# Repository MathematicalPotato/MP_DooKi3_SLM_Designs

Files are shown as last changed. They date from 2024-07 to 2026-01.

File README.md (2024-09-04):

# SLM parts for the X, Y, and Z Axis of DooKi3 or Annex Engineering K3
These files are designed to be SLM printed out of aluminum.  All files in this repo are still a WIP.  Do not order parts unless you are prepared for post-processing ill-fitting parts or worst-case scraping a whole batch of parts.

### !!! Please read all the notes in the READMEs for any parts you plan to order. !!!

## Notes
Please use the STLs for printing.  The CAD/STEP files are available in the event modifications are necessary for certain setups, but some print services cannot import STEP files and certain CAD files have been uploaded as assemblies and will not print properly if directly imported into print services.

There are a few different versions of the tensioning slider with different clearances.  At this time it is recommended to get the thickest version (+0.15) and sand to size. The machine will need a minimum of 7 tensioning sliders (4 for XY and 3 for Z).  As of August 20th 2024 the Z tensioners have been updated to V3 to allow for the use of up to 10mm belts and the XY tensioners have been updated to V4 to allow for the use of either 9/10mm belts or 12mm belts.  This 10mm version is recommended even for 9mm belts and requires the 10mm tensioning sliders. 9/10mm belts will also work with the 12mm parts, but they will be slightly heavier and won't have any othewr benefits besides allowing the use of 12mm belt.

## SLM XY Idlers - Live shafts and full sized pulleys:
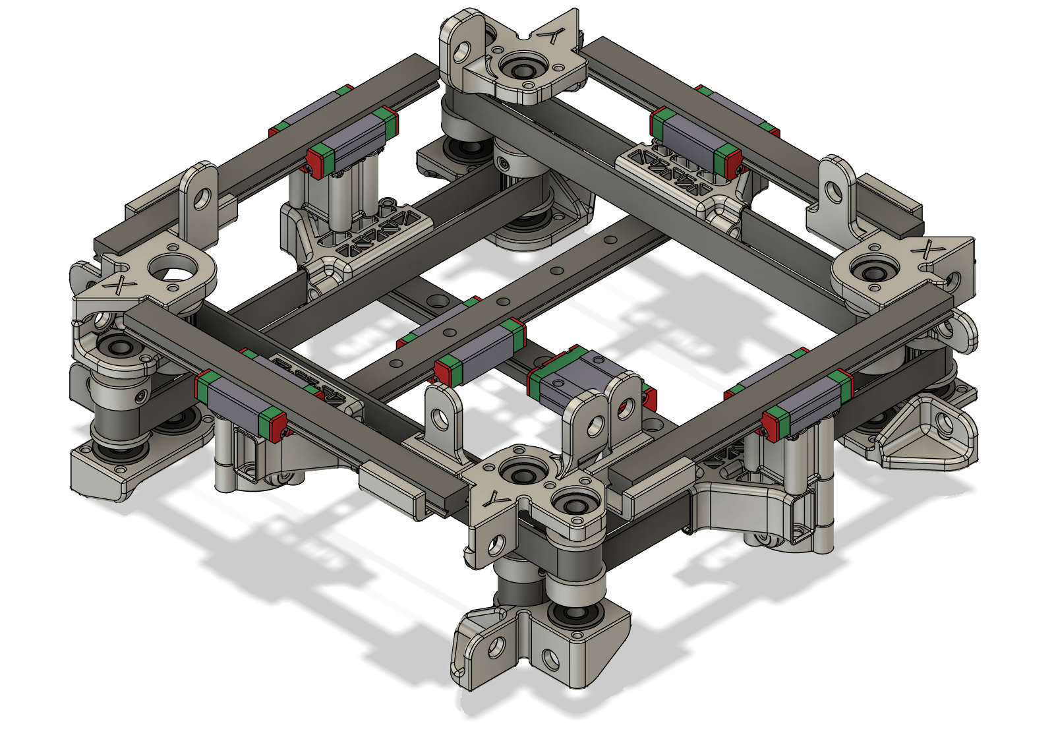
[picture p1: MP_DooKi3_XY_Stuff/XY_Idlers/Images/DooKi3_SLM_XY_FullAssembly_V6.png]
DooKi3_SLM_XY_Assembly

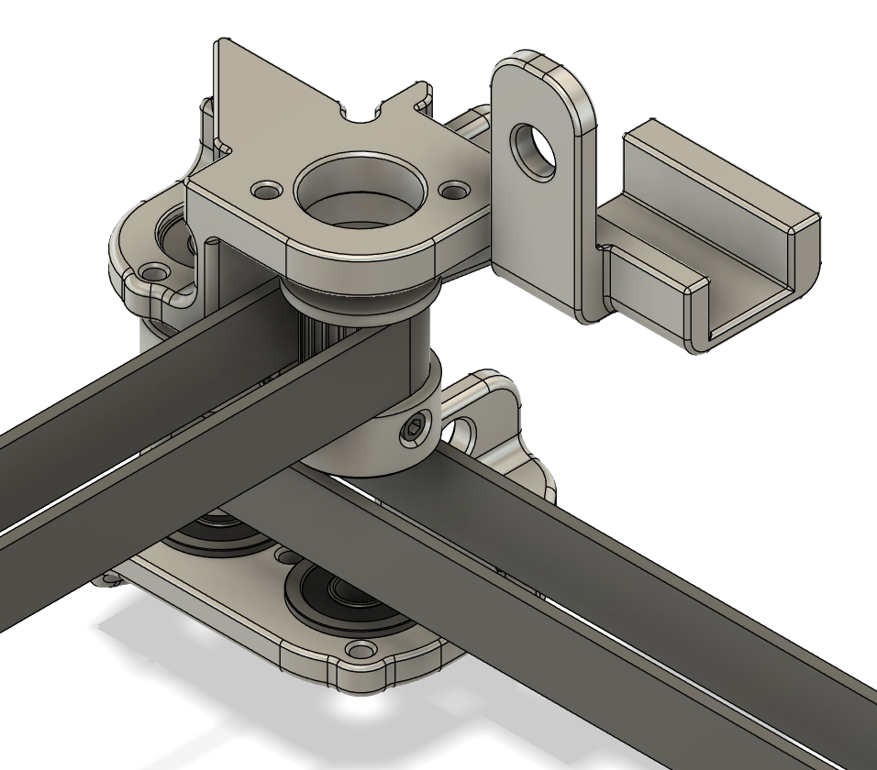
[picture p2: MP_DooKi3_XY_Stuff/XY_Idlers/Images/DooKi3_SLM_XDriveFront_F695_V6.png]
DooKi3_SLM_XDrive_F695

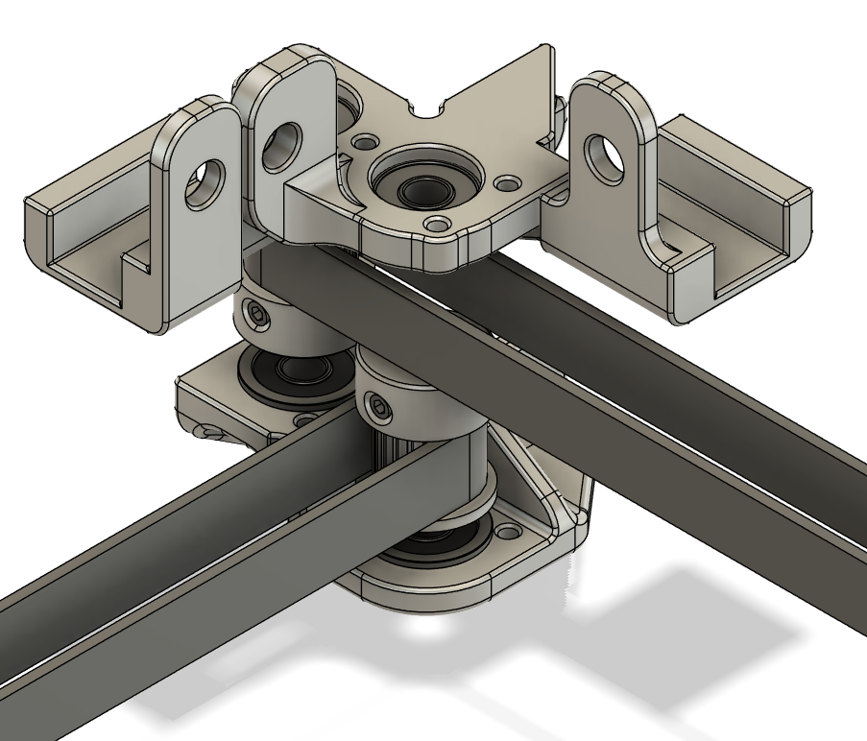
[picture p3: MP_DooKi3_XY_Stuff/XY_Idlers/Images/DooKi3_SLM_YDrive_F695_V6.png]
DooKi3_SLM_YDrive_F695


## SLM XY Tensioners
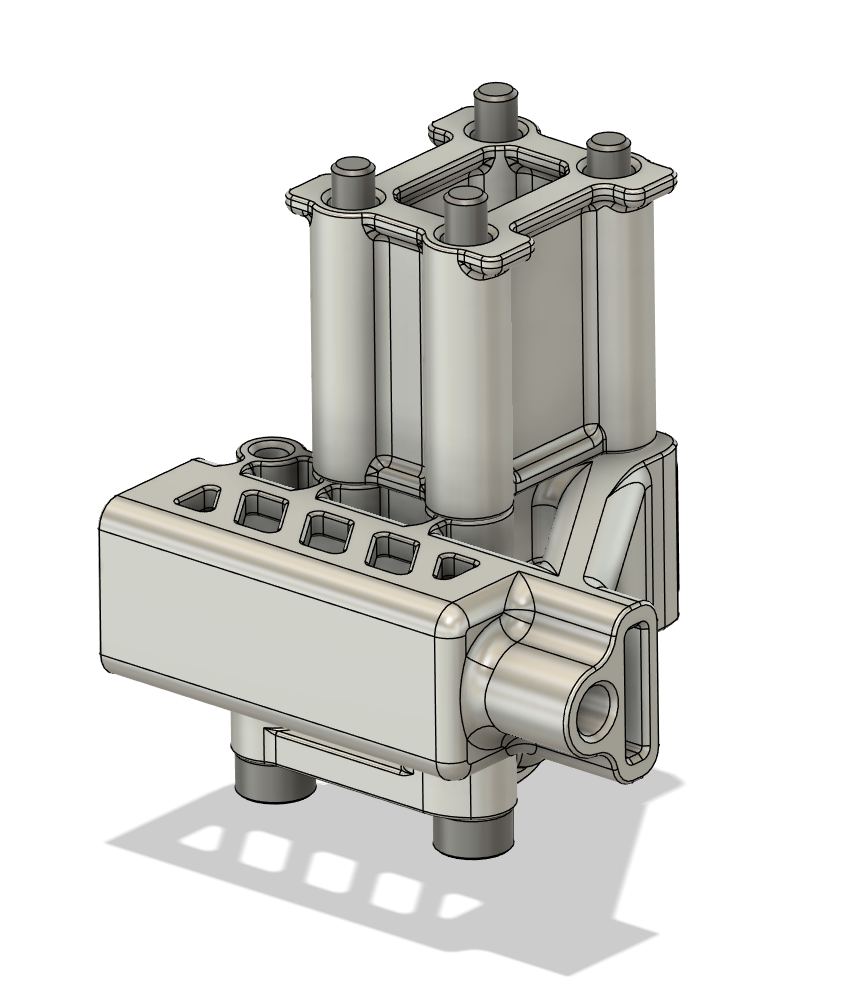
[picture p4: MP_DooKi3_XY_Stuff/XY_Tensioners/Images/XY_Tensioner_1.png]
XY_Tensioner_1

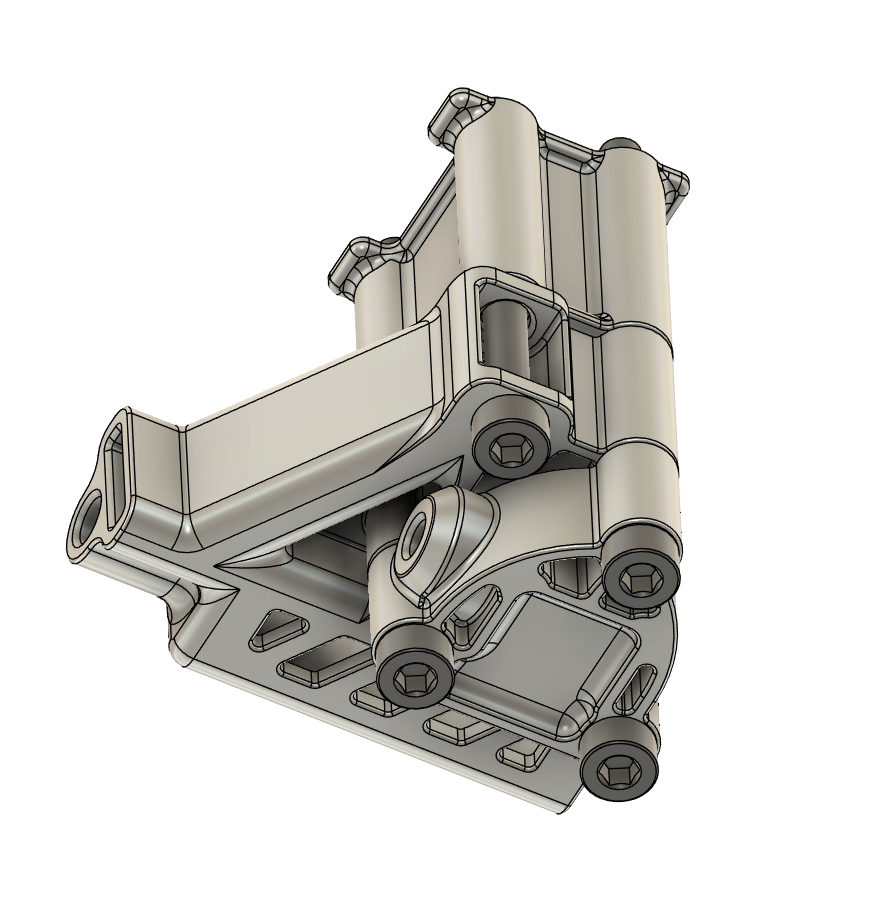
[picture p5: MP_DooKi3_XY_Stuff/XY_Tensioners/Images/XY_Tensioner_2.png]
XY_Tensioner_2

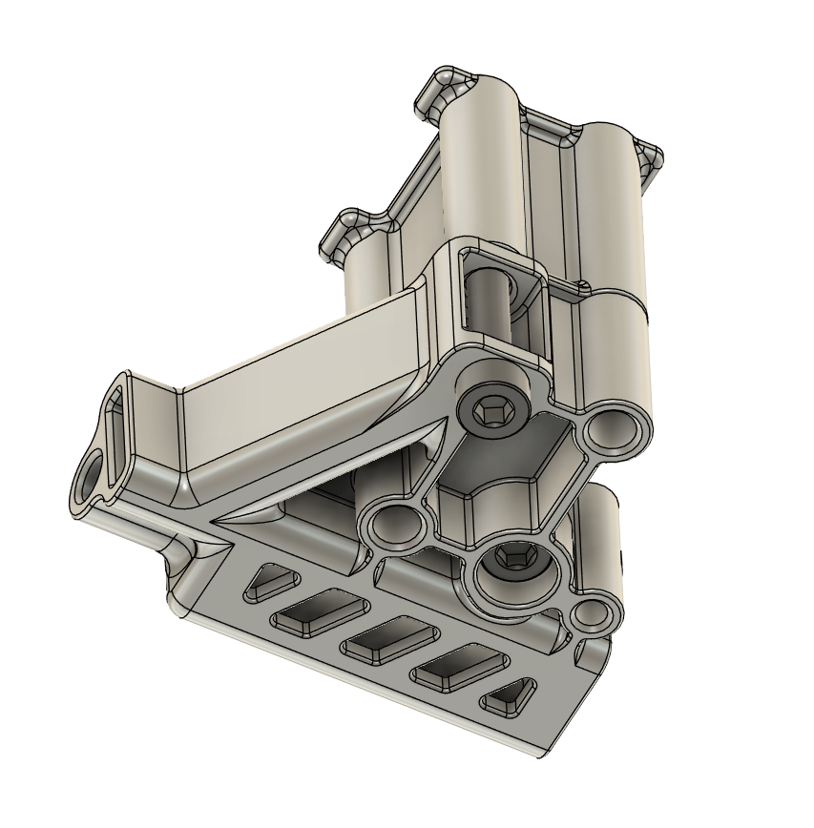
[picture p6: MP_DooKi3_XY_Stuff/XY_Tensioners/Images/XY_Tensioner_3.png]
XY_Tensioner_3


## SLM Z Maxwell Mounts and MGN9C Carriages
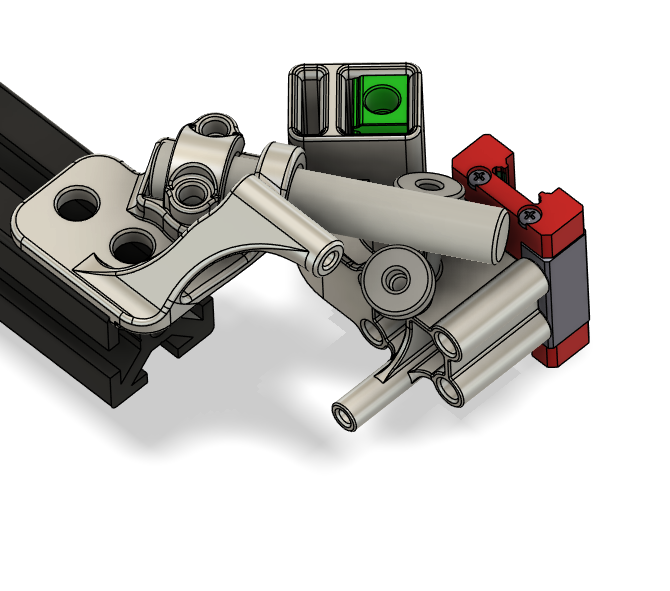
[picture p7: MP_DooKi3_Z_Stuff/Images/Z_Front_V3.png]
Z_Front

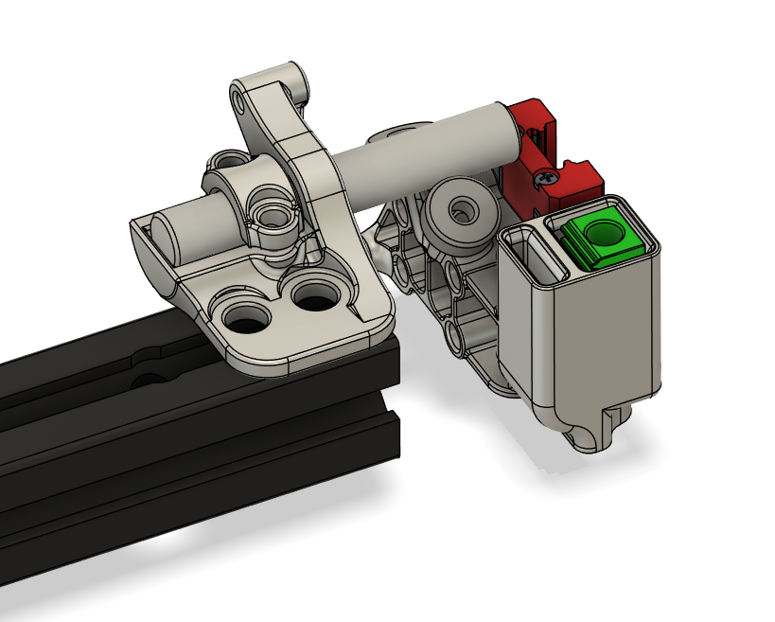
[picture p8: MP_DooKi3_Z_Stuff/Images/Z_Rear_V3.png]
Z_Rear


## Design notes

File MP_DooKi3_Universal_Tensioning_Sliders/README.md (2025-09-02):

# SLM Tensioning Sliders for X, Y, and Z Axes
These files are designed to be SLM printed out of aluminum.

## Notes
There are versions for 10mm (also compatible with 9mm) and 12mm belts.  Ensure you print the version for your XY setup.

These parts are oversized.  They will likely need sanded (on the side opposite the teeth) to ensure proper fitment belt retention.

Four sliders each have been combined into a single file for easier/cheaper printing.  They will need cut apart and sanded/filed to remove connecting the nubs. The Z Assembly will require one 10mm and XY will require either one 10mm or one 12mm depending on the XY tensioners ordered.

## Updates
### 2025-09-02
- Updated to V2
  - Added lightenting cutouts to make sanding to size easier and also reduce total part weight.

### 2024-09-26
- Updated thickness of sliders to require less sanding.

### 2024-08-20
- Updated to 4x combined sliders for 10mm and 12mm.

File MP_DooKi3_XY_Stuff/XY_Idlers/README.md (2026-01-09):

# SLM Printable XY Idlers for the Annex Engineering K3
These drives are designed to be SLM printed in aluminum (or other metals for $$$).  They allow for the toothed idlers to be changed to a full sized pulley with double shear.  Full sized bearings can take a lot more load than the smaller toothed idler bearings.  This should allow for full tension GT3 belts.

## Important Note

All bearings have been swapped to F695 (5mm shaft) or MF148 (8mm shaft).

The bearing holes are intentionally undersized.  In order to get a snug fit, you will need to first drill and then ream the holes to size.  All bearing locations have holes for M3 bolts for retention.  It is recommended to use M3x4 or M3x5 Button Head Cap Screws (BHCS).  There are 16 bearing locations and each will need 2-3 retaining bolts.  Retaining compound can also be used, but may make bearing removal difficult to impossible depending on the breakdown temperature of the compound used. 

The lower idler bodies will interfere with the stock FDM printed Z idlers.  It is recommended to only use these parts if you also have the SLM Z parts.

The endstops have been modeled together as one part to reduce print costs, the number of files, and to ensure they are matching heights.  The finished parts will need to be cut apart and sanded flat.  Only sand where the connecting nubs are present to avoid altering the overall length of the parts. 

### Approximate part weights
- MP_DooKi3_SLM_XY_V6_XDrive_Top: 18.1g
- MP_DooKi3_SLM_XY_V6_XDrive_BottomFront: 13.6g
- MP_DooKi3_SLM_XY_V6_XDrive_BottomRear: 13.1g
- MP_DooKi3_SLM_XY_V6_YDrive_Top: 15.6g
- MP_DooKi3_SLM_XY_V6_YDrive_Bottom: 17.5g
- MP_DooKi3_SLM_XY_V6_Endstops: 35g

## BOM
These lists are the recommended configurations for each belt setup.
### 9 or 10mm GT2 or GT3 belts
In addition to the stock four GT2 9mm pulleys you will need:
- 16 - F695 bearings for 5mm shafts
- 4 - additional GT2 9mm Pulleys with 5mm bore
- 4 - 37mm D cut 5mm diameter shafts (for the idler pulley)

### 12mm GT2 belts

IF YOU USE 12MM BELTS THE FOUR PULLEYS USED FOR THE DRIVE (MOTOR) SHAFTS WILL NEED APPROXIMATELY 1-2MM GROUND OFF THE BOTTOM (SET SCREW END) IN ORDER TO AVOID INTERFERENCE WITH THE BELTS.

In addition to the stock four GT2 9mm pulleys you will need:
- 16 - F695 bearings for 5mm shafts
- 4 - additional GT2 9mm pulleys with 5mm bore
- 4 - 37mm D cut 5mm diameter shafts (for the idler pulley)

### 12mm GT3 belts

1. IF YOU USE 12MM BELTS THE FOUR PULLEYS USED FOR THE DRIVE (MOTOR) SHAFTS WILL NEED APPROXIMATELY 1-2MM GROUND OFF THE BOTTOM (SET SCREW END) IN ORDER TO AVOID INTERFERENCE WITH THE BELTS.
2. 12MM GT3 BELTS REQUIRE VERY HIGH TENSION.  THIS SETUP IS NOT RECOMMENDED FOR STOCK 2020 K3 FRAMES.  A DooKi3-STYLE 4040 FRAME WOULD BE BETTER SUITED.

You will need:
- 16 - MF148 bearings for 8mm shafts
- 8 - additional GT2 12mm pulleys with 8mm bore.
- 4 - 37mm D cut 8mm diameter shafts (for the idler pulley)
- 4 - 60mm D cut 8mm diameter shafts (for drive pulley)
- 4 - Couplers to attach the motor, see Annex BOM for recommendations

## Updates
### 2024-10-12
- Reuploaded XDrive_BottomRear
  - Fixed half-broken chamfers.
### 2024-08-20
- Updated parts to V6
  - Converted to two part idlers instead of single part.  This should make them easier to print and post process (drill ream).
  - All parts now have holes where button-head cap screws (BHCS) can be used to retain the bearings.
  - The endstops have been combined into one printable file.
  - There are two lower parts for the X drives. One for the front left drive and one for the rear right drive. 

### 2024-08-07
- Reorganized the outdated parts folder and added version numbers for better tracking.
  - V1 are the original files
  - V2 have updated clearances and should be slightly lighter
- Updated XY idlers to V3 to allow for better clearances.
  - V3 will need the left Y rail shifted 10.5mm towards the front of the machine and the right Y rail shifted 10.5mm towards the rear of the machine.  This will allow for the idler stacks to be more easily removeable like the current Annex Engineering K3 625 bearing mounts.  All of the mounting bolts are oriented to thread into T-nuts in the vertical extrusions so shorter than standard allen wrenches are no longer needed.

## Images
### XY Assembly:
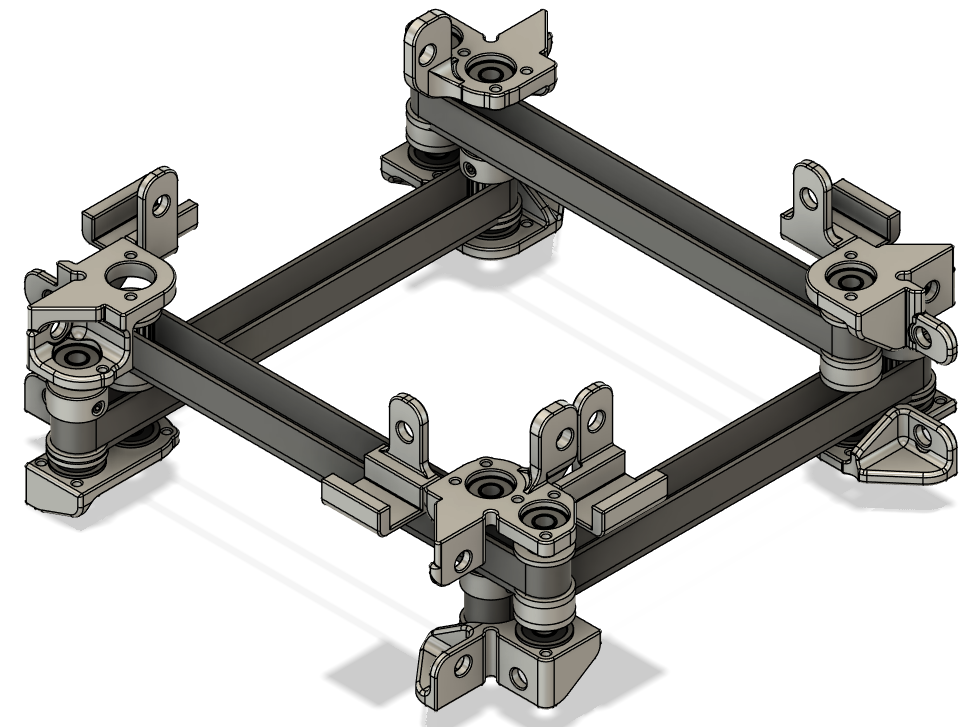
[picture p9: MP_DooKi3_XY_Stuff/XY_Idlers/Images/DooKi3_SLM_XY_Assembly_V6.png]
DooKi3_SLM_XY_Assembly


### X Drive:
DooKi3_SLM_XDriveFront_F695
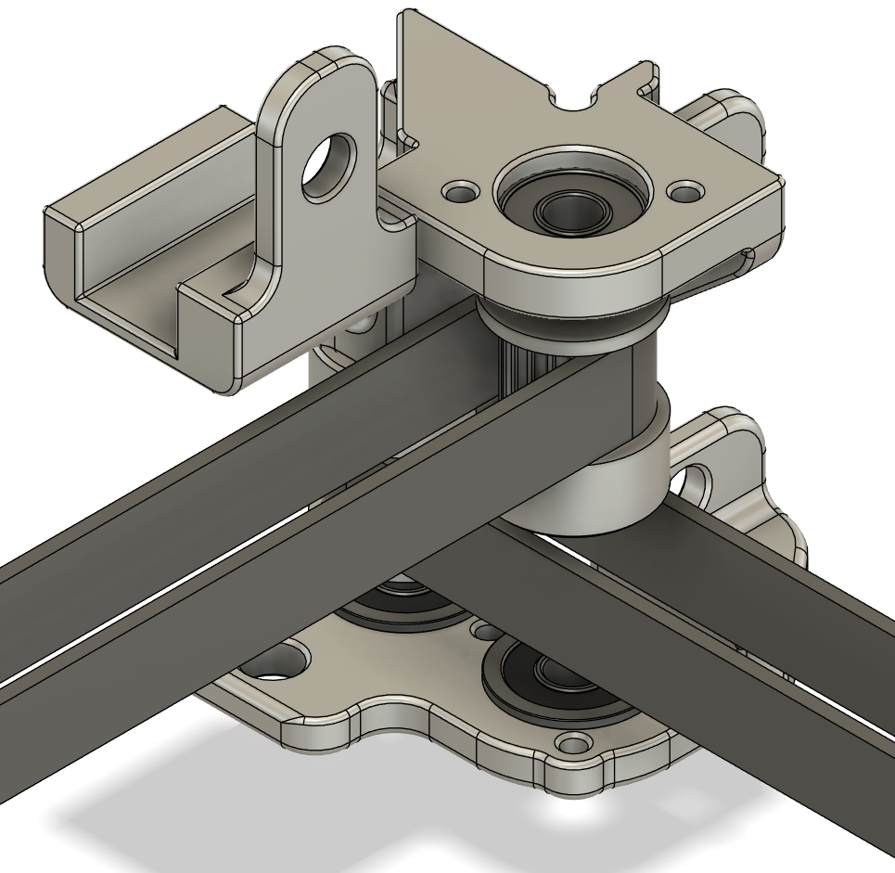
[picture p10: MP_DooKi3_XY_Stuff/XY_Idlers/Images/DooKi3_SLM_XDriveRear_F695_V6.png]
DooKi3_SLM_XDriveRear_F695


### Y Drive:
DooKi3_SLM_YDrive_F695

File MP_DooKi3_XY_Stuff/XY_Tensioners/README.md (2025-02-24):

# SLM XY Tensioner Stack for the Z Axis of DooKi3 or Annex Engineering K3
These files are designed to be SLM printed out of aluminum.

## Notes
There are Y Spacers are modeled as 20 or 21mm tall.  I orderd the 20mm and they came out as 20.3-20.4mm.  They will need sanded to the correct dimensions based on the rails and toolhead used for the machine.
The following Y Spacer thicknesses are required for a total toolhead plate thickness of 6.4mm: 
6.5mm thick rails = 19.9mm
6.0mm thick rails = 20.4mm
5.6mm thick rails = 20.8mm

The rail carriage mount only uses three bolts.  This allows the tensioner to remain installed with two bolts while the cross rails are removed so belt tension can be preserved during maintenance. There are many rail thickness options, it is recommended to get the size for your specific rails, however the smaller ones can be used with thicker rails if needed.  The larger options would need shims on the rails to work with smaller rails so it is not recommended to oversize.

These should be the approximate weights for these parts in aluminum:
- MP_DooKi3_SLM_XY_Tensioner_V4_10mm: 13.9g
- MP_DooKi3_SLM_XY_Tensioner_V4_12mm: 15.6g
- MP_DooKi3_SLM_XY_Rail_Mount_V2: 3.9g
- MP_DooKi3_SLM_Y_Spacer_V2: 6.2g

Total:
- 10mm X total: 17.8g per side
- 10mm Y total: 24.0g per side
- 12mm X total: 19.5g per side
- 12mm Y total: 25.7g per side

## Updates
### 2025-02-24
- Added additional rail mount sizes
  - 5.0mm thick rails
  - 5.5mm thick rails

### 2025-02-20
- Added additional rail mount sizes
  - 5.6mm thick rails
  - 6.0mm thick rails
- Added 21mm thick Y spacer

### 2024-10-29
- Updated tensioners to V6.
  - Increased wall thickness for 2.4mm tapping holes to allow better fitment for helicoils.

### 2024-09-06
- Updated tensioners to V5.
  - Widened belt slots to improve fitment and ease of insertion.
- Updated rail mounts to V4.
  - Widened rail and magnet spaces for better fitment and clearances.
 
### 2024-08-20
- Updated tensioners to V4.
  - This version adds tensioning parts that are compatible with 12mm wide belts.
    - 12mm will require the SLM idlers here: https://github.com/MathematicalPotato/MP_DooKi3_SLM_Designs/tree/main/MP_DooKi3_XY_Stuff/XY_Idlers.  See the README for additional considerations. 
  - This version mainly included CAD workflow changes to make the tensioners easier to modify in the future.  This version is slightly heavier as a result.

### 2024-08-07
- Reorganized the outdated parts folder and added version numbers for better tracking.
  - V1 are the original files.
  - V2 have updated clearances and should be slightly lighter.
- Updated XY tensioners to V3 to allow for the use of up to 10mm wide belts.
  - This version is also compatible with 9mm belts and is recommended for all belt thicknesses.
  - This version will require the use of the 10mm versions of the tensioning sliders.

## Images
XY_Tensioner_1
XY_Tensioner_2
XY_Tensioner_3

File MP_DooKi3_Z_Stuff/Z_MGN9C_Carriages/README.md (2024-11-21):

# SLM Z MGN9C Carriage Mounts for the Z Axis of DooKi3 or Annex Engineering K3
These files are designed to be SLM printed out of aluminum.

## Notes
Fronts will need M3x20 bolts for mounting instead of the stock M3x25.

These should be the approximate weights for these parts in aluminum:
- MP_DooKi3_SLM_Z_MGN9C_Front_V6: 19.9g
- MP_DooKi3_SLM_Z_MGN9C_Rear_V6: 18.5g

## Updates
### 2024-11-20
- Updated to V6
  - Added relief for the belt retention bolt heads so they can sit flat.

### 2024-10-29
- Updated to V5.
  - Increased wall thickness for 2.4mm tapping holes to allow for better fitment of helicoils.

### 2024-09-06
- Updated to V4.
  -Expanded belt paths for easier insertion.

### 2024-08-20
- Added STLs

### 2024-08-07
- Reorganized the outdated parts folder and added version numbers for better tracking.
  - V1 are the original files.
  - V2 have updated clearances and should be slightly lighter.
- Updated all Z MGN9C carriages to V3 to allow for the use of up to 10mm wide belts.
  - This version is also compatible with 9mm belts and is recommended for all belt thicknesses.
  - This version will require the use of the 10mm versions of the tensioning sliders.

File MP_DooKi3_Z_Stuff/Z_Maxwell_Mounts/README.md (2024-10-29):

# SLM Z Maxwell Mounts for the Z Axis of DooKi3 or Annex Engineering K3
These files are designed to be SLM printed out of aluminum.

## Notes
The 8mm shaft holes in the maxwell mounts may need bored out to fit the shaft.

The 8mm shafts are designed to be held in with M3 bolts as set screws and/or retaining compound.  There are holes that either be tapped for M3 or drilled and tapped for M3 helicoils.  Helicoils are recommended for longevity.

It is recommended to use the DXFs to get mild steel plates cut as clamps instead of using the SLM printable files.  Plates will be significantly cheaper and will be stronger as well.

These should be the approximate weights for these parts in aluminum:
- MP_DooKi3_SLM_Z_Maxwell_Front_V4: 10.4g
- MP_DooKi3_SLM_Z_Maxwell_Rear_V4: 9.8g
- MP_DooKi3_SLM_Z_Maxwell_Clamp_V4: 0.9g

## Updates
### 2024-10-29
- Updated mounts to V5
  - Adjusted alignment nubs so there is clearance for larger M5 T-nuts

### 2024-09-09
- Updated all parts to V4
  - Increased diameter of 8mm shaft hole to remove the need for drilling to size. 

### 2024-08-20
- Added STLs.

### 2024-08-07
- Reorganized the outdated parts folder and added version numbers for better tracking.
  - V1 are the original files
  - V2 have updated clearances and should be slightly lighter
- Updated all Z maxwell mounts to V3.
  - This version uses clamps instead of set screws to hold the shafts in place.  This removes the need for post-processing the 8mm shaft hole to ensure fitment.
  - Added indexing lips to the bottoms to help with alignment during installation.
  - There are two clamp designs:
    - MP_DooKi3_SLM_Z_Maxwell_ClampPlate_V3_x3.dxf
      - This version is the recommended option.  You will need to get this DXF lasercut.  Mild steel in 3mm thickness is recommended as it should be cheaper and stronger than aluminum.
    - MP_DooKi3_SLM_Z_Maxwell_Clamp_V3_x3.step
      - This version is designed to be SLM printed. It will be more expensive and has the potential to be weaker depending on material choice.

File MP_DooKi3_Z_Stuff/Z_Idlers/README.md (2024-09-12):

# SLM Z Idlers for the Z Axis of DooKi3 or Annex Engineering K3
These files are designed to be SLM printed out of aluminum.

## Notes
The shaft holes may need bored out to fit the idler shafts.

The shafts can held in with M3 set screws and/or retaining compound.  There are holes that either be tapped for M3 or drilled and tapped for M3 helicoils.  Helicoils are recommended for longevity.

All idlers will need two M3x4 set screws. The rear idler uses three M5x8 BHCS or SHCS for mounting. The fronts each use three M5x10 SHCS.

These should be the approximate weights for these parts in aluminum:

- MP_DooKi3_SLM_Z_Idler_Front: 14.5g
- MP_DooKi3_SLM_Z_Idler_Rear: 22.5g

## Updates
### 2024-09-12
- Updated Rear to V5 to allow use of either M5x8 BHCS or SHCS.  Fronts must use M5x10 SHCS

### 2024-08-20
- Added STLs.
- Updated Fronts to V5 and Rear to V4.  The Fronts are slightly shorter to allow for the updated SLM XY Idlers.
  - They are still fully compatible with stock and allow full travel.
  - The rear has been revised to be reversible.  This allows it to work with stock setups (idler positioned at the top) or setups with very long hotends (idler positioned at the bottom).
  - Weights have been significantly reduced for all as well.

### 2024-08-07
- Reorganized the outdated parts folder and added version numbers for better tracking.
  - V1 are the original files
  - V2 have updated clearances and should be slightly lighter
- Updated the front Z idlers to V3 with chamfers added to have better clearances.

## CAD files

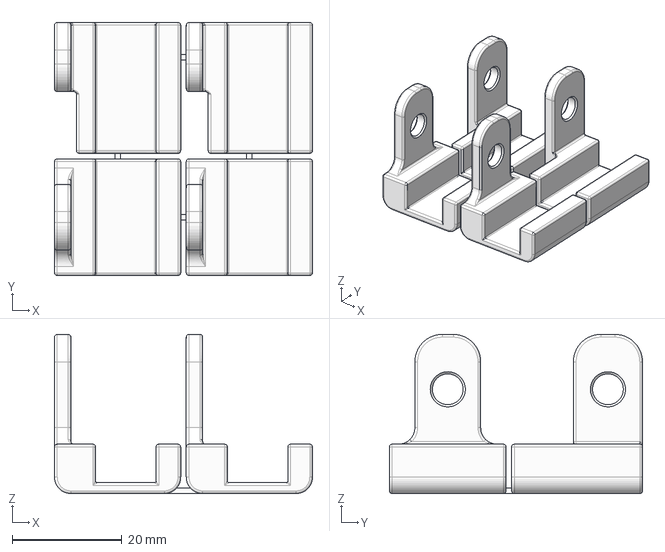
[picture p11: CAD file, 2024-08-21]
MP_DooKi3_XY_Stuff/XY_Idlers/CAD/MP_DooKi3_SLM_XY_V6_Endstops_x1.step
47.0 x 46.1 x 29.0 mm

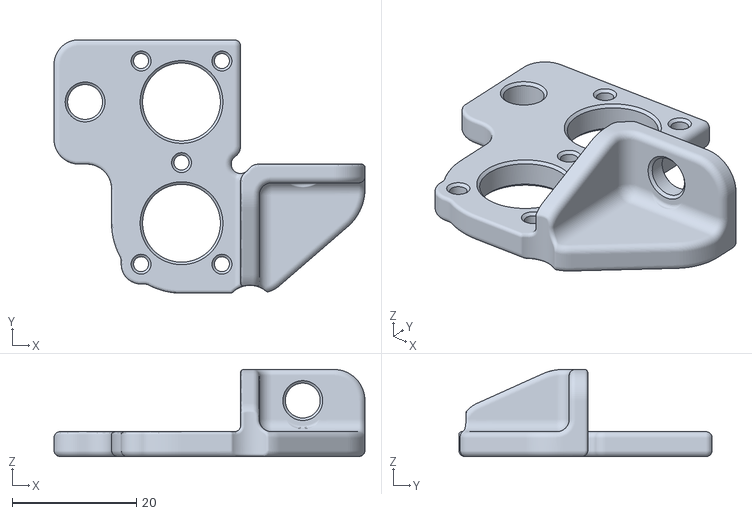
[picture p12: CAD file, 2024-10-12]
MP_DooKi3_XY_Stuff/XY_Idlers/STLs/MP_DooKi3_SLM_XY_V6_XDrive_BottomRear_x1.stl
50.0 x 40.8 x 14.0

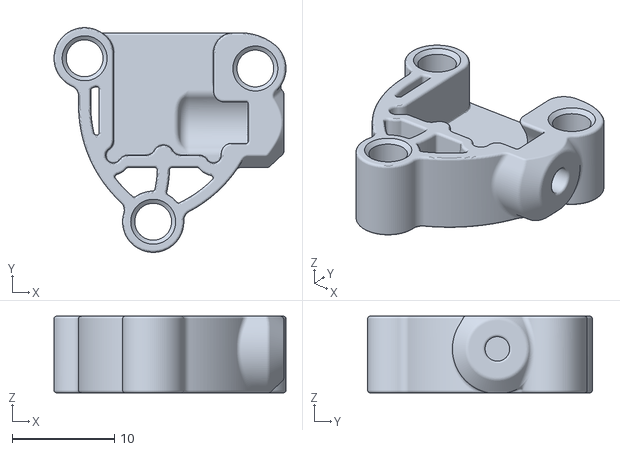
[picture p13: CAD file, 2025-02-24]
MP_DooKi3_XY_Stuff/XY_Tensioners/STLs/MP_DooKi3_SLM_XY_5.0mm_Rail_Mount_V3_Mirror_x2.stl
22.7 x 22.0 x 7.50

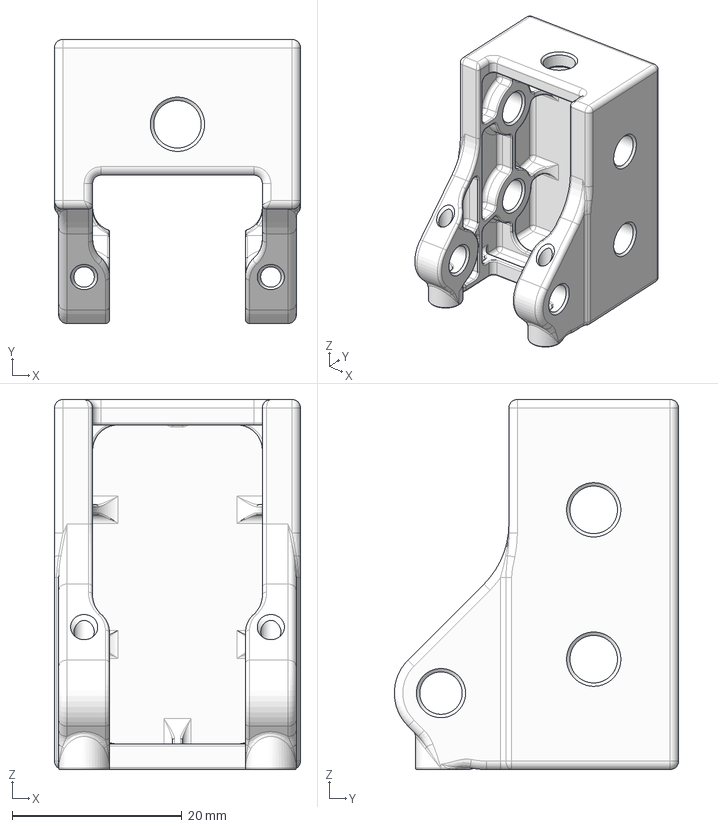
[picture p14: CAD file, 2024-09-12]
MP_DooKi3_Z_Stuff/Z_Idlers/CAD/MP_DooKi3_SLM_Z_Idler_Rear_V5.step
29.0 x 33.5 x 43.6 mm

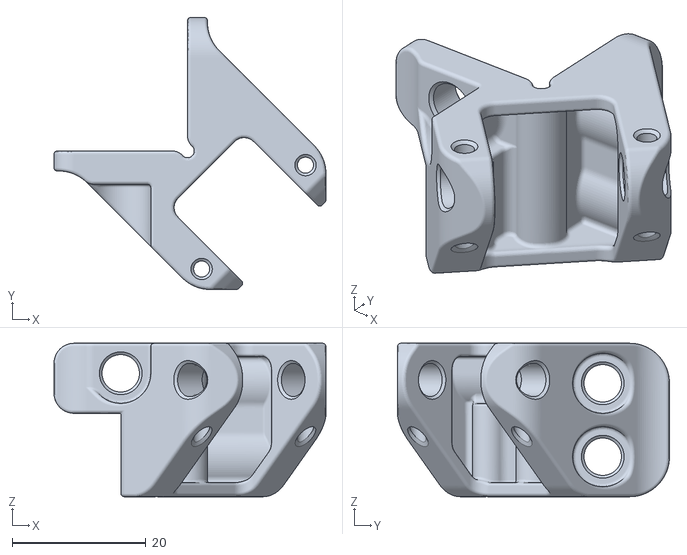
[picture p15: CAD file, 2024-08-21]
MP_DooKi3_Z_Stuff/Z_Idlers/STLs/MP_DooKi3_SLM_Z_Idler_Front_Mirror_V5.stl
40.8 x 40.8 x 23.0

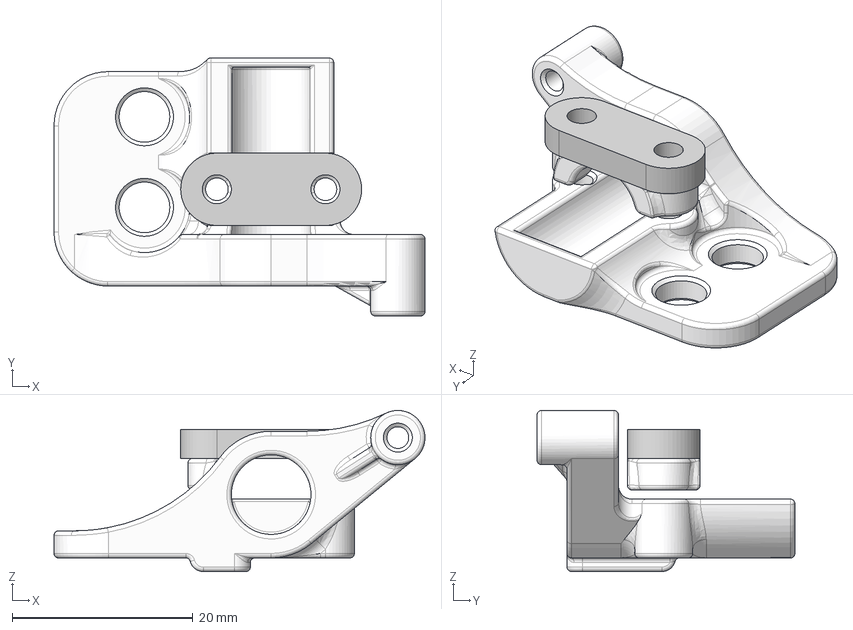
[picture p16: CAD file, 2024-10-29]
MP_DooKi3_Z_Stuff/Z_Maxwell_Mounts/CAD/MP_DooKi3_SLM_Z_Maxwell_Rear_V5.step
41.0 x 28.5 x 17.8 mm
MP_DooKi3_SLM_Z_Maxwell_Clamp_V3
MP_DooKi3_SLM_Z_Maxwell_Mount_Rear_V5
MP_DooKi3_SLM_Z_Maxwell_ClampPlate_V3

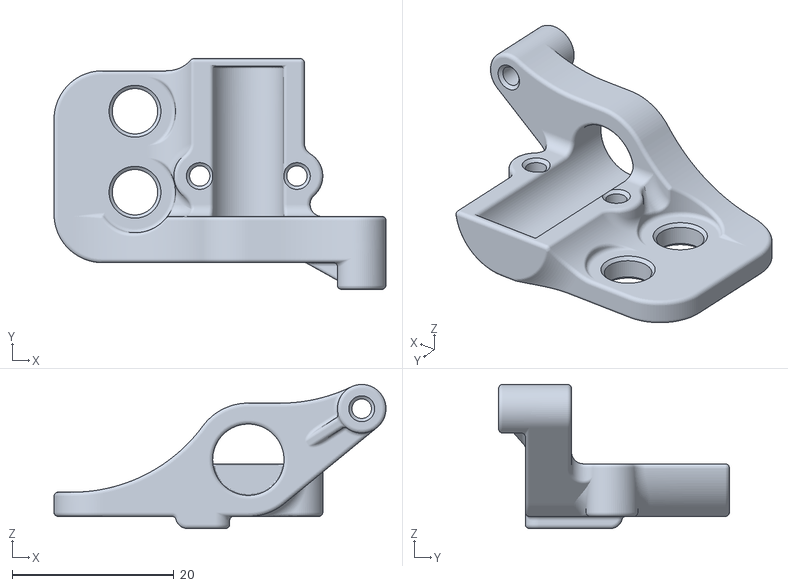
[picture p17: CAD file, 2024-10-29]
MP_DooKi3_Z_Stuff/Z_Maxwell_Mounts/STLs/MP_DooKi3_SLM_Z_Maxwell_Mount_Rear_V5.stl
41.0 x 28.5 x 17.8

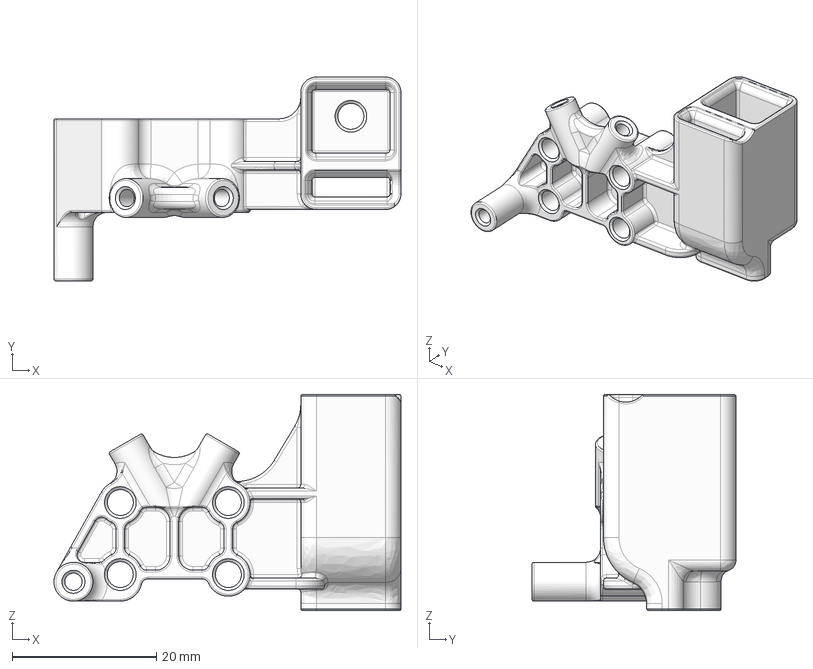
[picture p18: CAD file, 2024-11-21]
MP_DooKi3_Z_Stuff/Z_MGN9C_Carriages/CAD/MP_DooKi3_SLM_Z_MGN9C_Rear_V6.step
48.1 x 28.3 x 30.0 mm

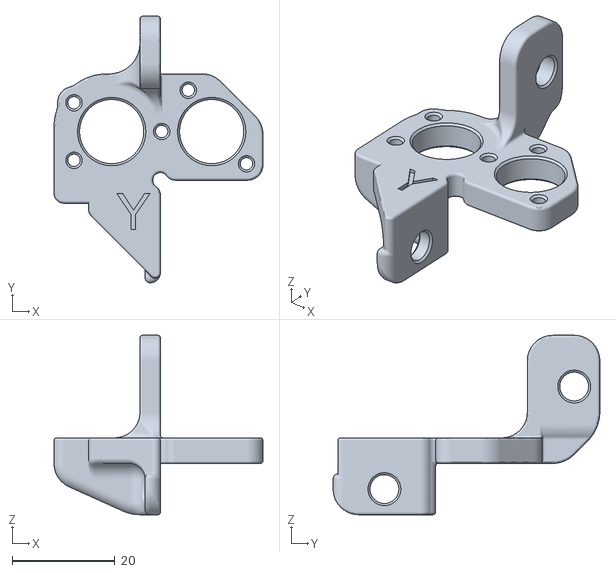
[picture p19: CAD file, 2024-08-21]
MP_DooKi3_XY_Stuff/XY_Idlers/STLs/MP_DooKi3_SLM_XY_V6_YDrive_Top_x2.stl
40.8 x 52.0 x 35.0

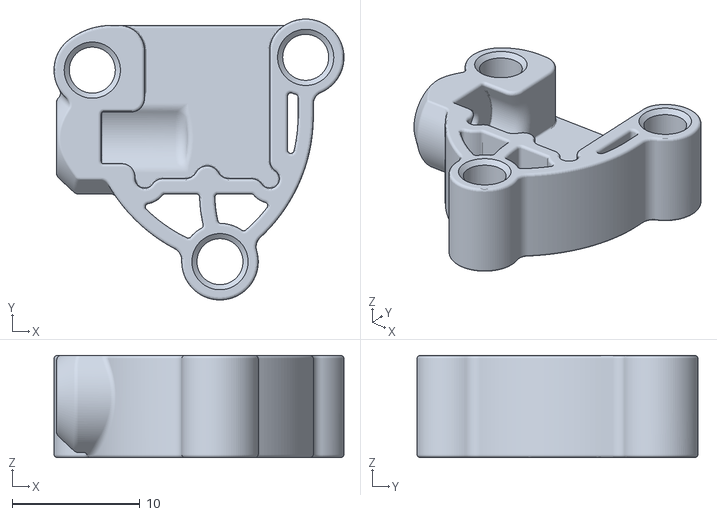
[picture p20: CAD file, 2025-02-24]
MP_DooKi3_XY_Stuff/XY_Tensioners/STLs/MP_DooKi3_SLM_XY_5.5mm_Rail_Mount_V3_x2.stl
22.7 x 22.0 x 8.00

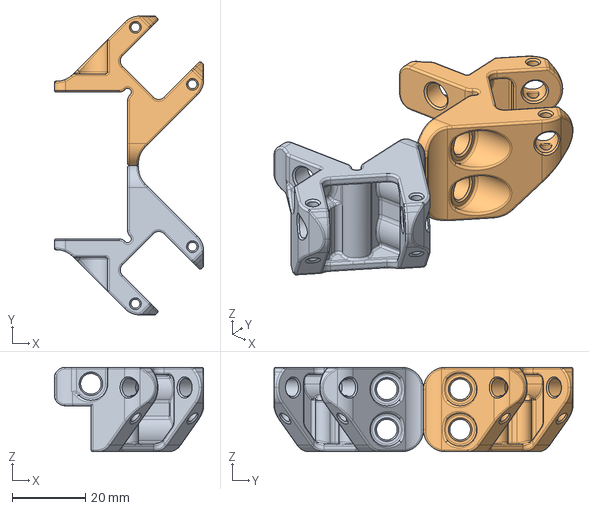
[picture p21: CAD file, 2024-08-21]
MP_DooKi3_Z_Stuff/Z_Idlers/CAD/MP_DooKi3_SLM_Z_Idler_Front_V5.step
40.8 x 81.5 x 23.0 mm

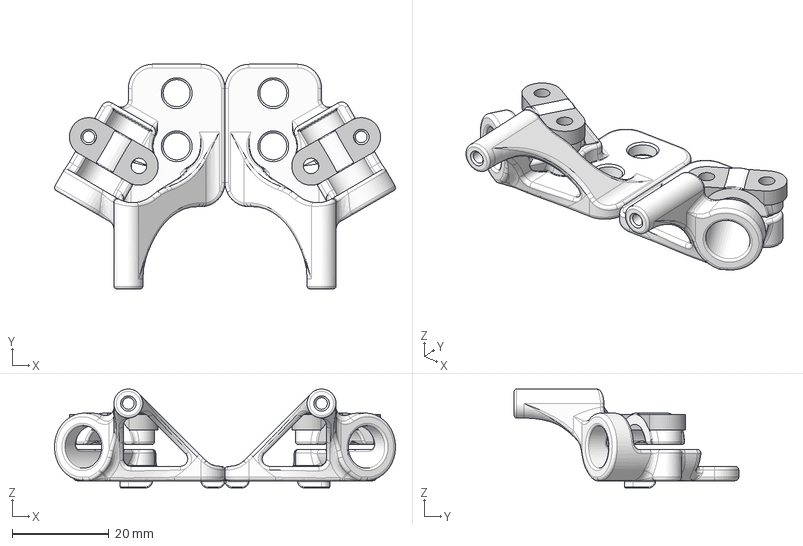
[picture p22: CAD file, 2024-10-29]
MP_DooKi3_Z_Stuff/Z_Maxwell_Mounts/CAD/MP_DooKi3_SLM_Z_Maxwell_Front_V5.step
70.6 x 46.5 x 20.5 mm
MP_DooKi3_SLM_Z_Maxwell_ClampPlate_V3
MP_DooKi3_SLM_Z_Maxwell_Mount_Front_V3
MP_DooKi3_SLM_Z_Maxwell_Mount_Front_Mirror_V3
MP_DooKi3_SLM_Z_Maxwell_Clamp_V3
MP_DooKi3_SLM_Z_Maxwell_ClampPlate_V3(Mirror)
MP_DooKi3_SLM_Z_Maxwell_Clamp_V3 v1(Mirror)

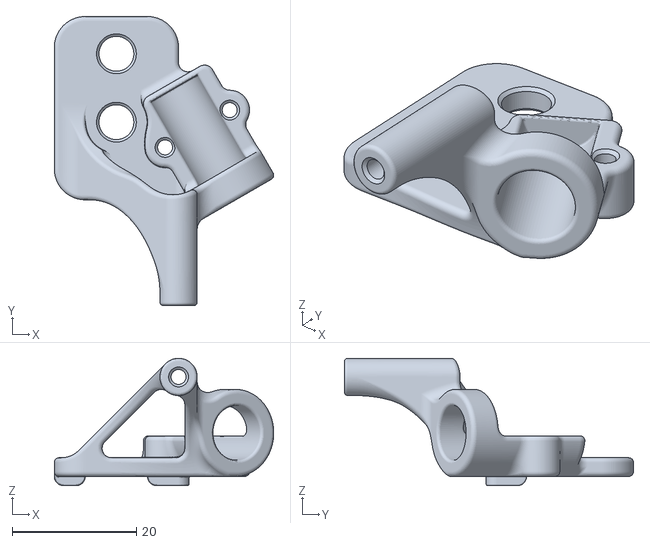
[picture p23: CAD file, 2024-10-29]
MP_DooKi3_Z_Stuff/Z_Maxwell_Mounts/STLs/MP_DooKi3_SLM_Z_Maxwell_Mount_Front_V5.stl
35.3 x 46.5 x 20.5

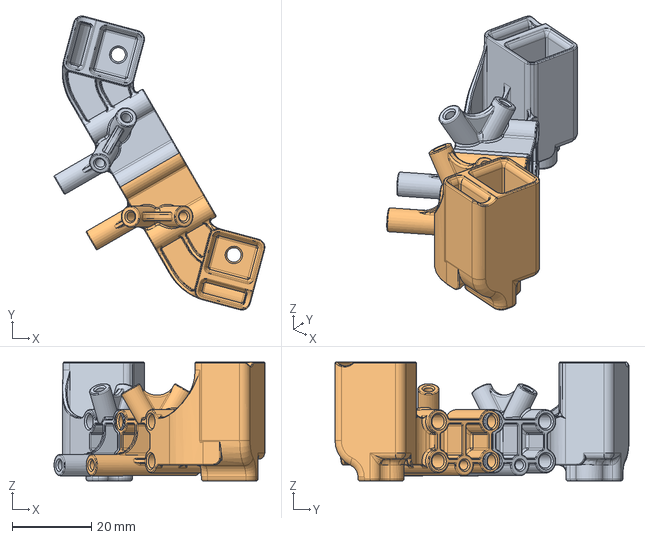
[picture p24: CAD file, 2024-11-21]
MP_DooKi3_Z_Stuff/Z_MGN9C_Carriages/CAD/MP_DooKi3_SLM_Z_MGN9C_Front_V6.step
53.2 x 74.2 x 30.0 mm

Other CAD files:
MP_DooKi3_XY_Stuff/XY_Idlers/STLs/MP_DooKi3_SLM_XY_V6_XDrive_BottomFront_x1.stl
MP_DooKi3_XY_Stuff/XY_Tensioners/STLs/MP_DooKi3_SLM_XY_5.0mm_Rail_Mount_V3_x2.stl
MP_DooKi3_Z_Stuff/Z_Maxwell_Mounts/CAD/MP_DooKi3_SLM_Z_Maxwell_ClampPlate_V3_x3.dxf
MP_DooKi3_Z_Stuff/Z_Maxwell_Mounts/STLs/MP_DooKi3_SLM_Z_Maxwell_Mount_Front_Mirror_V5.stl
MP_DooKi3_Universal_Tensioning_Sliders/CAD/Outdated/MP_DooKi3_SLM_Tensioning_Slider_10mm_+0.05_x7.step
MP_DooKi3_Universal_Tensioning_Sliders/CAD/Outdated/MP_DooKi3_SLM_Tensioning_Slider_10mm_+0.10_x7.step
MP_DooKi3_Universal_Tensioning_Sliders/CAD/Outdated/MP_DooKi3_SLM_Tensioning_Slider_10mm_+0.15_x7.step
MP_DooKi3_Universal_Tensioning_Sliders/CAD/Outdated/MP_DooKi3_SLM_Tensioning_Slider_10mm_x7.step
MP_DooKi3_Universal_Tensioning_Sliders/CAD/Outdated/MP_DooKi3_SLM_Tensioning_Slider_12mm_+0.15_x7.step
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

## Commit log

2024-07-26 Update and rename MP_DooKi3_SLM_Tensioning_Slider_x3.step to MP_DooKi3_SLM_Tensioning_Slider_x7.step
    [MP_DooKi3_SLM_Tensioning_Slider_x7.step]
2024-07-26 Update and rename MP_DooKi3_SLM_Tensioning_Slider_x3_+0.1.step to MP_DooKi3_SLM_Tensioning_Slider_x7_+0.1.step
    [MP_DooKi3_SLM_Tensioning_Slider_x7_+0.1.step]
2024-07-26 Update and rename MP_DooKi3_SLM_Tensioning_Slider_x3_+0.05.step to MP_DooKi3_SLM_Tensioning_Slider_x7_+0.05.step
    [MP_DooKi3_SLM_Tensioning_Slider_x7_+0.05.step]
2024-07-26 Update and rename MP_DooKi3_SLM_Tensioning_Slider_x3_+0.15.step to MP_DooKi3_SLM_Tensioning_Slider_x7_+0.15.step
    [MP_DooKi3_SLM_Tensioning_Slider_x7_+0.15.step]
2024-07-29 Update and rename MP_DooKi3_SLM_XY_Rail_Mount.step to MP_DooKi3_SLM_XY_Rail_Mount_x2.step
    [MP_DooKi3_SLM_XY_Rail_Mount_x2.step]
2024-07-29 Update and rename MP_DooKi3_SLM_XY_Rail_Mount_Mirror.step to MP_DooKi3_SLM_XY_Rail_Mount_Mirror_x2.step
    [MP_DooKi3_SLM_XY_Rail_Mount_Mirror_x2.step]
2024-07-29 Update and rename MP_DooKi3_SLM_XY_Tensioner.step to MP_DooKi3_SLM_XY_Tensioner_x2.step
    [MP_DooKi3_SLM_XY_Tensioner_x2.step]
2024-07-29 Update and rename MP_DooKi3_SLM_XY_Tensioner_Mirror.step to MP_DooKi3_SLM_XY_Tensioner_Mirror_x2.step
    [MP_DooKi3_SLM_XY_Tensioner_Mirror_x2.step]
2024-08-07 Update and rename MP_DooKi3_SLM_Z_Maxwell_Rear_V3_x3.step to MP_DooKi3_SLM_Z_Maxwell_Rear_V3.step
    [MP_DooKi3_SLM_Z_Maxwell_Rear_V3.step]
2024-08-21 Update and rename MP_DooKi3_SLM_XY_Rail_Mount_Mirror_V2_x2.step to MP_DooKi3_SLM_XY_Rail_Mount_V2_Mirror_x2.step
    [MP_DooKi3_SLM_XY_Rail_Mount_V2_Mirror_x2.step]
2024-08-21 Update and rename MP_DooKi3_SLM_XY_Tensioner_Mirror_V3_x2.step to MP_DooKi3_SLM_XY_Tensioner_V3_Mirror_x2.step
    [MP_DooKi3_SLM_XY_Tensioner_V3_Mirror_x2.step]
2026-07-21 Add files via upload
    Updated corner hole that mates against extrusions. Less sharp corners
2026-07-21 Rename MP_DooKi3_SLM_XY_V6_Endstops_x1.stl to MP_DooKi3_SLM_XY_V7_Endstops_x1.stl
    Renamed to V7 to match others files, no changes to file
2026-07-21 Add files via upload
    Updated files to V7. Holes/slot in corner that mates to extrusion made less sharp/aggressive
2026-07-21 Add files via upload
    Uploaded drawings to be used for reaming with 3d print services that allow it.
